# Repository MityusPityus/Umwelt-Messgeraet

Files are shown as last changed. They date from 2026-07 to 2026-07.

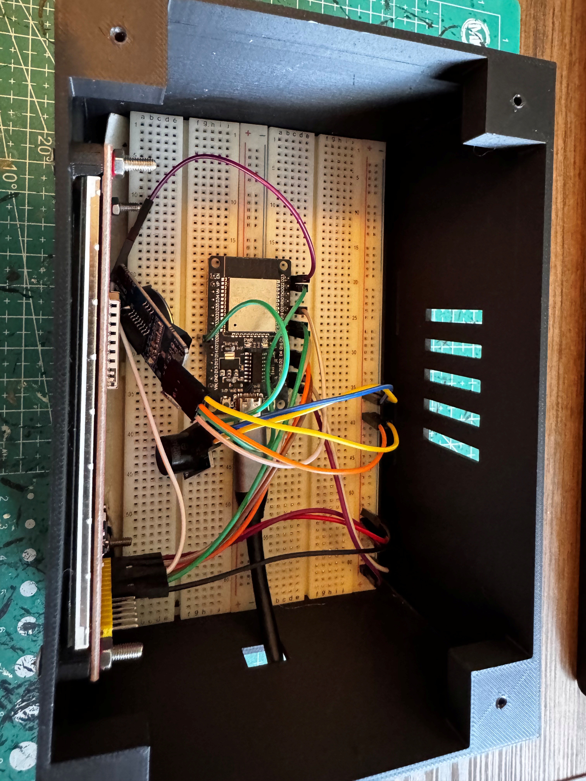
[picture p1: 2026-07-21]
docs/Bilder/Body.jpg

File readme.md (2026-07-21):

# ESP32 Umweltmessstation

Dieses Projekt umfasst die Entwicklung einer offlinefähigen Umweltmessstation auf Basis eines ESP32.

Die Umweltstation misst verschiedene Raumklimawerte, zeigt diese auf einem 4-Zoll-TFT-Display an und kann bei schlechter Luftqualität eine akustische Warnung ausgeben. Zusätzlich besitzt das Gerät eine Touch-Bedienung, eine lokale Datenspeicherung, Statistikfunktionen und ein 3D-gedrucktes Gehäuse.

## Funktionen

- Messung von Temperatur
- Messung der Luftfeuchtigkeit
- Messung des Luftdrucks
- Bewertung der Luftqualität über den Gaswert des BME680
- Anzeige von Uhrzeit und Datum über ein DS3231 RTC-Modul
- Offline-Betrieb ohne Internetverbindung
- Touch-Bedienung über XPT2046
- Akustischer Alarm über Buzzer bei schlechter Luftqualität
- Alarm-Quittierung über Button
- Lokale Messwertspeicherung mit LittleFS
- Statistikansicht für Tages- und 24h-Durchschnitt
- Graphanzeige der letzten 24 Stunden
- Alarm-Protokoll mit Zeitstempel und Messwerten
- Individuell konstruiertes 3D-Gehäuse

## Verwendete Hardware

| Komponente | Zweck |
|---|---|
| ESP32 Dev Board | Zentrale Steuereinheit |
| BME680 | Messung von Temperatur, Feuchtigkeit, Druck und Gaswert |
| DS3231 RTC | Offline-Uhrzeit und Datum |
| ST7796S TFT Display | Anzeige der Messwerte |
| XPT2046 Touchcontroller | Touch-Bedienung |
| Aktiver Buzzer | Akustischer Alarm |
| Push Button | Alarm quittieren |
| 3D-gedrucktes Gehäuse | Schutz und Montage der Komponenten |

## Software-Funktionen

Die Hauptsoftware liest regelmäßig die Sensordaten aus, aktualisiert das Display und bewertet die Luftqualität anhand des Gaswiderstands. Bei schlechter Luftqualität wird ein Alarm ausgelöst, der über einen Button quittiert werden kann.

Die Messwerte werden lokal im internen Flash-Speicher des ESP32 über LittleFS gespeichert. Dadurch ist keine Internetverbindung notwendig. Die gespeicherten Werte werden für Statistik- und Graphfunktionen verwendet.

## Kalibrierung

Während des Projekts wurden die Messwerte mit einem externen Hygrometer verglichen.

Ermittelte Abweichungen:

- Temperatur: Sensor zeigte ca. 3,6 °C zu hoch
- Luftfeuchtigkeit: Sensor lag ca. 3,4 % unter dem Vergleichswert
- Gaswert:
  - Fenster offen: ca. 132,5 kOhm
  - Fenster geschlossen: ca. 88,7 kOhm
  - angepustet: ca. 60 kOhm

Daraus wurden folgende Luftqualitätsbereiche abgeleitet:

| Gaswert | Bewertung |
|---|---|
| >= 100 kOhm | Gut |
| 70 - 99,9 kOhm | Mittel |
| < 70 kOhm | Schlecht |

## Projektstatus

Aktueller Stand:

- Hardware aufgebaut
- RTC-Modul erfolgreich ausgetauscht
- Display und Touch funktionieren
- Sensorwerte werden angezeigt
- Statistik- und Graphfunktionen sind integriert
- Alarm-Protokoll ist integriert
- Gehäuse wurde gedruckt und montiert
- Kurzzeit- und Plausibilitätstests wurden durchgeführt

Der geplante 24h-Dauertest konnte aus Zeitgründen vor der Präsentation nicht vollständig durchgeführt werden. Stattdessen wurde ein mehrstündiger Funktionstest mit Vergleichsmessungen durchgeführt.

## Repository-Struktur

```text
docs/
  Projektdokumentation und Bilder

hardware/
  Bauteilliste, Verkabelung und Hinweise

software/
  Hauptprogramm der Umweltstation

tests/
  Einzeltests für Display, Touch, RTC und BME680

3d-modelle/
  OpenSCAD- und STL-Dateien für das Gehäuse

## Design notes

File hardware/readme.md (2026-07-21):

# Hardware

Dieser Ordner enthält alle hardwarebezogenen Informationen der Umweltmessstation.

## Inhalte

### Bauteilliste.md

Übersicht aller verwendeten Komponenten.

### Verkabelung.md

Dokumentation der Pinbelegung und Verdrahtung zwischen den einzelnen Komponenten.

### Schaltplan.png

Grafische Darstellung der elektrischen Verschaltung des Systems.

## Verwendete Hauptkomponenten

- ESP32 Dev Board
- BME680 Sensor
- DS3231 RTC Modul
- ST7796S Display
- XPT2046 Touchcontroller
- Aktiver Buzzer
- Push Button
- 3D-gedrucktes Gehäuse

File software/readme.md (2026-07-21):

# Software

In diesem Ordner befindet sich der Hauptcode der ESP32 Umweltmessstation.

## Hauptfunktionen

- Initialisierung von Display, Touch, BME680 und RTC
- Anzeige aktueller Messwerte
- Bewertung der Luftqualität
- Alarmfunktion über Buzzer
- Alarmquittierung über Button
- Touch-Navigation
- Statistikscreen
- 24h Graphscreen
- Alarm-Protokoll
- Speicherung der Messwerte mit LittleFS

## Wichtig

Der aktuelle Code verwendet für die Präsentation ein kurzes Speicherintervall:

```cpp
const unsigned long logInterval = 30000;

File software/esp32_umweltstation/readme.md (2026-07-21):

# ESP32 Umweltmessstation Software

Diese Software steuert die komplette Umweltmessstation.

## Hauptfunktionen

### Sensorik

Auslesen des BME680 Sensors:

- Temperatur
- Luftfeuchtigkeit
- Luftdruck
- Gaswert

### Echtzeituhr

Verwendung eines DS3231 RTC-Moduls für:

- Uhrzeit
- Datum

Die Uhr funktioniert vollständig offline und benötigt keine Internetverbindung.

### Anzeige

Darstellung der Messwerte auf einem ST7796S 4-Zoll-TFT-Display.

Angezeigt werden:

- Temperatur
- Luftfeuchtigkeit
- Luftdruck
- Luftqualität
- Uhrzeit
- Datum

### Touchbedienung

Der XPT2046 Touchcontroller ermöglicht:

- Öffnen der Statistikansicht
- Öffnen des 24h-Graphen
- Öffnen des Alarmprotokolls
- Navigation zwischen den Ansichten

### Luftqualitätsbewertung

Die Luftqualität wird anhand des Gaswiderstands des BME680 bewertet.

| Gaswert | Bewertung |
|---|---|
| >= 100 kOhm | Gut |
| 70 - 99.9 kOhm | Mittel |
| < 70 kOhm | Schlecht |

### Alarmfunktion

Bei schlechter Luftqualität:

- Aktivierung des Buzzers
- Anzeige einer Warnung auf dem Display

Der Alarm kann über einen Taster quittiert werden.

### Datenspeicherung

Die Messdaten werden lokal im Flash-Speicher gespeichert.

Verwendete Technologie:

- LittleFS

Die Speicherung erfolgt ohne Internetverbindung.

### Statistik

Folgende Statistiken stehen zur Verfügung:

- Durchschnittswerte des aktuellen Tages
- Durchschnittswerte der letzten 24 Stunden

### Graph

Grafische Darstellung der letzten 24 Stunden für:

- Temperatur
- Luftfeuchtigkeit
- Luftdruck
- Gaswert

### Alarmprotokoll

Speicherung von Alarmereignissen mit:

- Zeitstempel
- Temperatur
- Luftfeuchtigkeit
- Luftdruck
- Gaswert

## Verwendete Bibliotheken

- Adafruit_GFX
- Adafruit_ST7796S
- Adafruit_BME680
- Adafruit_Sensor
- RTClib
- XPT2046_Touchscreen
- LittleFS

## Hauptdatei

```text
esp32_umweltstation.ino

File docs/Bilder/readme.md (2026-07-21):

# Bilder

Dieser Ordner enthält Grafiken, Screenshots und Fotos, die während der Entwicklung der Umweltmessstation erstellt wurden.

## Enthaltene Dateien

### Schaltplan.png

Schaltplan der Umweltmessstation.

Der Schaltplan dokumentiert die elektrische Verbindung zwischen:

- ESP32
- BME680 Sensor
- DS3231 RTC
- ST7796S Display
- XPT2046 Touchcontroller
- Buzzer
- Taster

## Geplante Ergänzungen

Zusätzlich sollen folgende Bilder dokumentiert werden:

- Aufbau auf dem Arbeitstisch
- Verkabelung der Komponenten
- Fertiges Gehäuse
- Hauptbildschirm
- Statistikansicht
- 24h-Graph
- Alarmprotokoll
``

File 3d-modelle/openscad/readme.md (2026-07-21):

# OpenSCAD Modell

Dieser Ordner enthält die CAD-Datei des Gehäuses für die ESP32 Umweltmessstation.

## Datei

### esp32_umweltstation_case.scad

OpenSCAD-Modell des Gehäuses.

Das Gehäuse wurde speziell für die verwendeten Komponenten entwickelt:

- ESP32
- ST7796S 4 Zoll Display
- XPT2046 Touchscreen
- BME680 Sensor
- DS3231 RTC Modul
- Buzzer
- Taster

## Eigenschaften

- Frontausschnitt für das Display
- Befestigungspunkte für die Elektronik
- Öffnungen für Sensorbelüftung
- Öffnung für USB-Kabel
- Platz für RTC und Sensor
- Verschraubbares Gehäuse

## Software

Zur Bearbeitung der CAD-Datei wurde OpenSCAD verwendet.

https://openscad.org

## Hinweis

Die OpenSCAD-Datei stellt die Master-Datei dar und kann für zukünftige Anpassungen weiter bearbeitet werden.

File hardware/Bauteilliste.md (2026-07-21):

# Bauteilliste

## Elektronik

| Komponente | Anzahl | Funktion |
|---|---|---|
| ESP32 Dev Board | 1 | Hauptcontroller |
| BME680 | 1 | Temperatur, Feuchtigkeit, Druck, Gas |
| DS3231 RTC | 1 | Uhrzeit und Datum |
| ST7796S 4 Zoll Display | 1 | Anzeige |
| XPT2046 Touchcontroller | 1 | Touchbedienung |
| Aktiver Buzzer | 1 | Akustische Warnung |
| Push Button | 1 | Alarm quittieren |
| USB Kabel | 1 | Stromversorgung |

## Mechanik

| Komponente | Anzahl |
|---|---|
| Gehäuse Oberteil | 1 |
| Gehäuse Unterteil | 1 |
| Schrauben | 4 |

## Software-Bibliotheken

- Adafruit_GFX
- Adafruit_ST7796S
- Adafruit_BME680
- RTClib
- XPT2046_Touchscreen
- LittleFS

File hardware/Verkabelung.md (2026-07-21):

# Verkabelung

## Display ST7796S

| Pin | ESP32 |
|---|---|
| VCC | 3.3V |
| GND | GND |
| LED | 3.3V |
| SCK | GPIO18 |
| SDI | GPIO23 |
| CS | GPIO5 |
| DC | GPIO2 |
| RST | GPIO4 |

## Touch XPT2046

| Pin | ESP32 |
|---|---|
| CLK | GPIO18 |
| DIN | GPIO23 |
| DO | GPIO19 |
| CS | GPIO27 |
| IRQ | GPIO14 |

## BME680

| Pin | ESP32 |
|---|---|
| SDA | GPIO21 |
| SCL | GPIO22 |
| VCC | 3.3V |
| GND | GND |

## RTC DS3231

| Pin | ESP32 |
|---|---|
| SDA | GPIO21 |
| SCL | GPIO22 |
| VCC | 3.3V |
| GND | GND |

## Buzzer

GPIO26

## Alarmbutton

GPIO13

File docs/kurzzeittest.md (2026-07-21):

# Kurzzeittest

Ein vollständiger 24h Dauertest konnte vor der Präsentation nicht durchgeführt werden.

Stattdessen wurde ein mehrstündiger Test durchgeführt.

## Geprüfte Funktionen

- Display
- Touch
- RTC
- BME680
- Statistik
- Graphanzeige
- Alarmprotokoll
- Buzzer
- Button

## Ergebnis

Alle Kernfunktionen arbeiteten stabil.

Die Sensorwerte wurden erfolgreich mit einem externen Hygrometer verglichen.

Die Luftqualitätsbewertung wurde durch verschiedene Tests überprüft:

- Fenster offen
- Fenster geschlossen
- Angepusteter Sensor

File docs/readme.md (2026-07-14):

# Dokumentation

Enthält Projektdokumentation, Fehleranalysen und Arbeitsprotokolle.

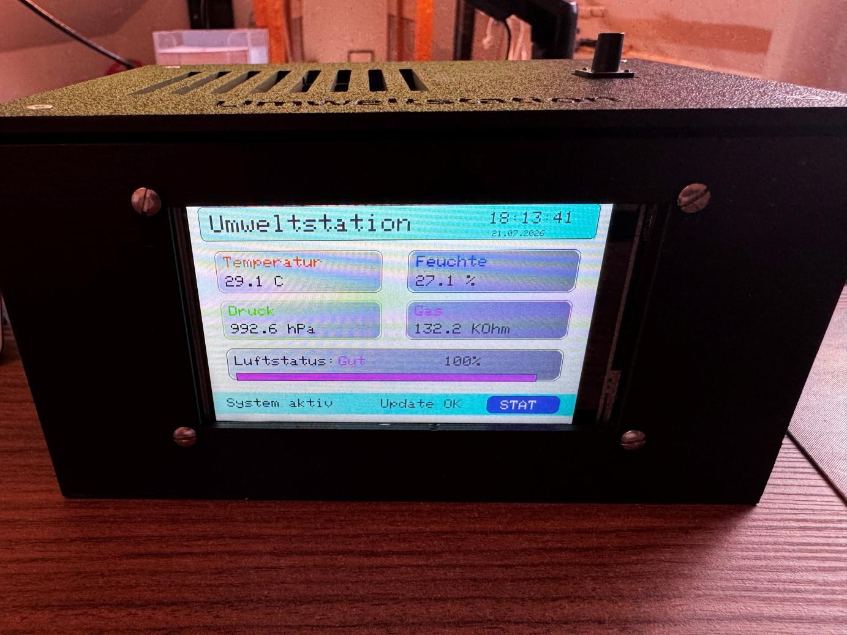
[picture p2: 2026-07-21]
assets/scrumboard-2.png

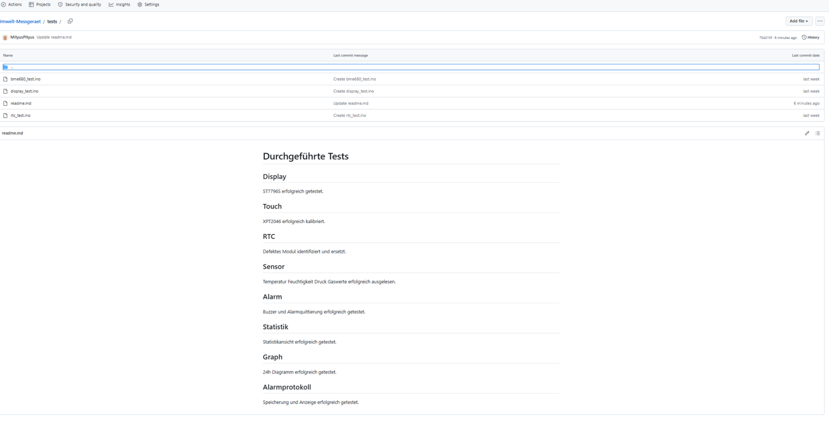
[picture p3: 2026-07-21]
assets/doku-bild-2.jpg

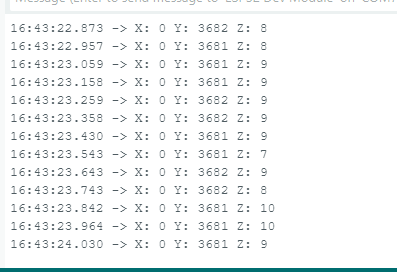
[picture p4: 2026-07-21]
assets/doku-bild-4.jpg

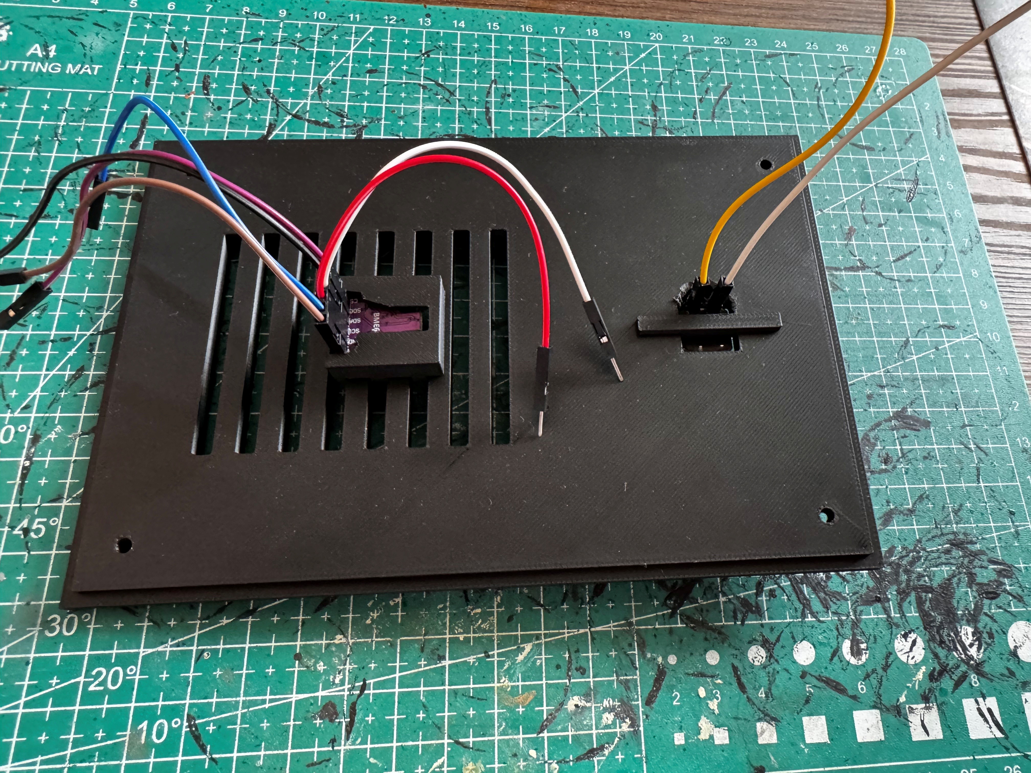
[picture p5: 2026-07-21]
docs/Bilder/Lid.jpg

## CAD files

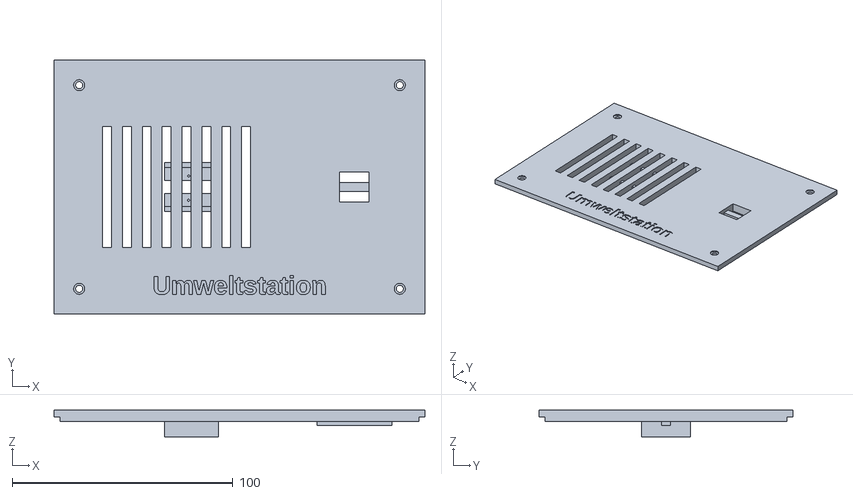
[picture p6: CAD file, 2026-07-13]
3d-modelle/stl/esp32_umweltstation_lid.stl
168.0 x 115.0 x 12.0

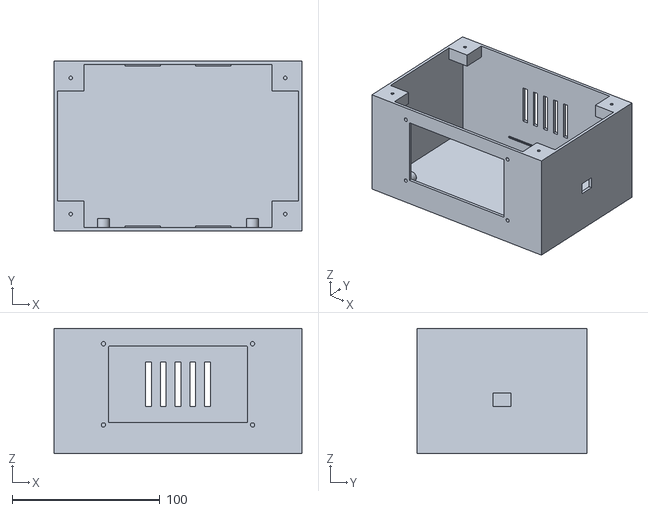
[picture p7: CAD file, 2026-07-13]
3d-modelle/stl/esp32_umweltstation_body.stl
168.0 x 115.0 x 85.0

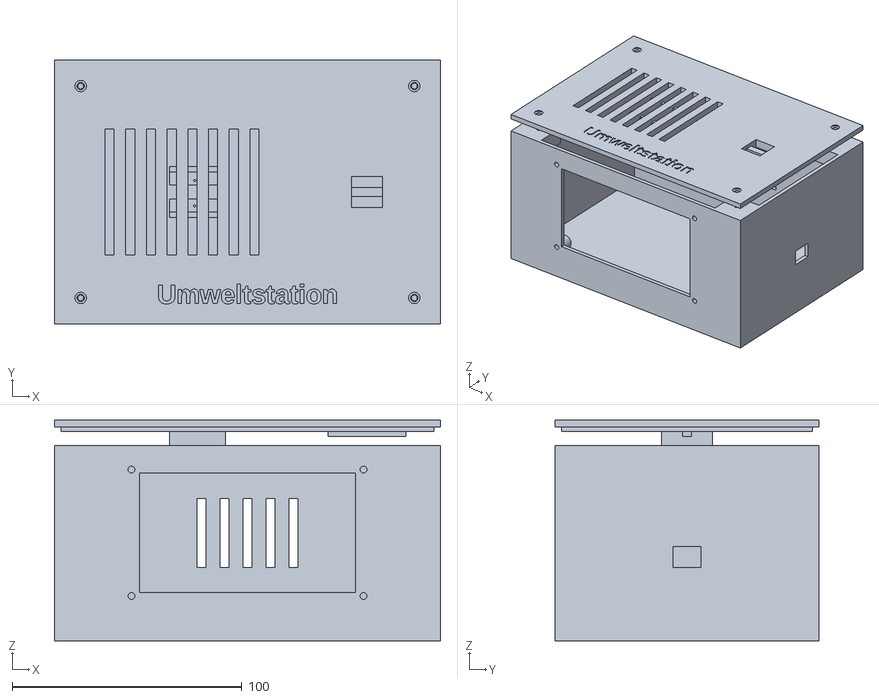
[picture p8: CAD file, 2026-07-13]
3d-modelle/stl/esp32_umweltstation_case.v2.stl
168.0 x 115.0 x 96.0

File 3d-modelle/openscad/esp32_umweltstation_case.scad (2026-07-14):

// ESP32 Umweltstation Gehaeuse V13.6
// Einheiten: mm
// OpenSCAD:
// PART = "preview" -> Vorschau
// PART = "body"    -> Unterteil exportieren
// PART = "lid"     -> Deckel exportieren

PART = "preview"; // "body", "lid", "preview"

// =====================================================
// Hauptmasse
// =====================================================
case_w = 168;
case_d = 115;
case_h = 85;

wall = 2.4;
lid_t = 3.0;
clearance = 0.4;

// =====================================================
// Gravuren
// =====================================================
engraving_enabled = true;

lid_text = "Umweltstation";
lid_text_size = 8.5;
lid_engrave_depth = 0.5;
lid_text_x = case_w / 2;
lid_text_y = 13;

body_bottom_text = "Mityu - Prototype";
body_text_size = 7.0;
body_engrave_depth = 0.5;
body_text_x = case_w / 2;
body_text_y = case_d / 2;

// =====================================================
// Display vorne
// =====================================================
display_center_z = 47;

display_view_w = 94;
display_view_h = 52;

display_pocket_w = 112;
display_pocket_h = 64;
display_recess_depth = 8.5;

display_hole_dx = 101;
display_hole_dz = 55;
display_screw_d = 3.0;

display_post_d = 8.0;
display_post_depth = 6.0;

// =====================================================
// USB rechts
// =====================================================
usb_slot_w = 12;
usb_slot_h = 9;
usb_slot_z = 32;

// =====================================================
// Hintere Zusatz-Lueftung
// =====================================================
// Kleine Schlitze hinten mittig fuer bessere Durchlueftung.
back_vent_count = 5;
back_vent_w = 4;
back_vent_h = 30;
back_vent_gap = 6;
back_vent_center_x = case_w / 2;
back_vent_z = 32;

// =====================================================
// Breadboard Niederhalter / Anti-Wackel-Lippen
// Start jetzt bei 12.7 mm, damit Breadboard leichter reingeht.
// =====================================================
breadboard_clips_enabled = true;

bb_clip_w = 24;
bb_clip_d = 1.0;
bb_clip_h = 0.9;
bb_clip_z = 12.7;
bb_clip_inset_x = 48;

// =====================================================
// Button oben
// =====================================================
button_hole = 13.5;
button_x = case_w - 32;
button_y = case_d / 2;

// Durchgehende Support-Bar fuer Button
button_bar_w = 4;
button_bar_l = 34;
button_bar_h = 4;
button_bar_z = -button_bar_h;

// =====================================================
// Lueftung oben
// =====================================================
vent_count = 8;
vent_w = 4;
vent_l = 55;
vent_gap = 5;
vent_x0 = 22;
vent_y = case_d / 2;

// =====================================================
// Deckelschrauben / Body-Halter
// =====================================================
lid_screw_d = 3.2;
top_boss_pilot_d = 2.5;

top_boss_size = 18;
top_boss_h = 10;
top_boss_z = case_h - top_boss_h;

screw_offset = wall + top_boss_size / 2;

// =====================================================
// BME680 Einschub-Halter am Deckel
// Sensor ca. 20 x 20 x 4 mm
// Links offen fuer Pins/Kabel.
// Innenhoehe ca. 9 mm.
// =====================================================
sensor_board_w = 20;
sensor_board_d = 20;

sensor_clearance = 2.0;

sensor_mount_x = 50;
sensor_mount_y = case_d / 2 - (sensor_board_d + sensor_clearance) / 2;

sensor_slot_w = sensor_board_w + sensor_clearance;
sensor_slot_d = sensor_board_d + sensor_clearance;

sensor_rail_wall = 2.2;
sensor_rail_h = 9.0;

sensor_lip_w = 8.0;
sensor_lip_h = 1.2;

sensor_stop_w = 2.5;

// Kleine Einrast-Nupsis fuer Sensorloecher
// - Durchmesser 1 mm
// - Abstand 11 mm
// - erster Nupsi 5 mm von der ersten Seitenwand/Lippe entfernt
// - zweiter Nupsi 11 mm weiter
sensor_peg_enabled = true;
sensor_peg_d = 1.0;
sensor_peg_h = 4.0;
sensor_peg_spacing = 11.0;
sensor_peg_first_offset = 5.0;

// =====================================================
// Sonstiges
// =====================================================
cut_depth = 20;
holder_overlap = 0.8;

$fn = 48;

// =====================================================
// Positionen Deckelschrauben
// =====================================================
module lid_screw_positions() {
    positions = [
        [screw_offset, screw_offset],
        [case_w - screw_offset, screw_offset],
        [screw_offset, case_d - screw_offset],
        [case_w - screw_offset, case_d - screw_offset]
    ];

    for (p = positions) {
        translate([p[0], p[1], 0])
            children();
    }
}

// =====================================================
// Positionen Display-Schrauben vorne
// =====================================================
module display_screw_positions_front() {
    for (sx = [-1, 1]) {
        for (sz = [-1, 1]) {
            translate([
                case_w / 2 + sx * display_hole_dx / 2,
                0,
                display_center_z + sz * display_hole_dz / 2
            ])
            children();
        }
    }
}

// =====================================================
// Hintere Lueftungsschlitze
// =====================================================
module back_vents_cutout() {
    total_w = back_vent_count * back_vent_w + (back_vent_count - 1) * back_vent_gap;
    start_x = back_vent_center_x - total_w / 2;

    for (i = [0 : back_vent_count - 1]) {
        translate([
            start_x + i * (back_vent_w + back_vent_gap),
            case_d - wall - 2,
            back_vent_z
        ])
            cube([
                back_vent_w,
                wall + 6,
                back_vent_h
            ]);
    }
}

// =====================================================
// Deckel-Gravur oben
// =====================================================
module lid_engraving_cut() {
    if (engraving_enabled) {
        translate([
            lid_text_x,
            lid_text_y,
            lid_t - lid_engrave_depth
        ])
            linear_extrude(height = lid_engrave_depth + 0.3)
                text(
                    lid_text,
                    size = lid_text_size,
                    halign = "center",
                    valign = "center",
                    font = "Liberation Sans:style=Bold"
                );
    }
}

// =====================================================
// Boden-Gravur Body unten
// =====================================================
module body_bottom_engraving_cut() {
    if (engraving_enabled) {
        translate([
            body_text_x,
            body_text_y,
            -0.1
        ])
            linear_extrude(height = body_engrave_depth + 0.3)
                text(
                    body_bottom_text,
                    size = body_text_size,
                    halign = "center",
                    valign = "center",
                    font = "Liberation Sans:style=Bold"
                );
    }
}

// =====================================================
// Gehaeuse-Schale
// =====================================================
module shell_only() {
    difference() {
        cube([case_w, case_d, case_h]);

        // Innenraum offen nach oben
        translate([wall, wall, wall])
            cube([
                case_w - 2 * wall,
                case_d - 2 * wall,
                case_h - wall + 1
            ]);

        // Sichtbares Displayfenster vorne
        translate([
            (case_w - display_view_w) / 2,
            -1,
            display_center_z - display_view_h / 2
        ])
            cube([
                display_view_w,
                wall + 3,
                display_view_h
            ]);

        // Displaytasche innen
        translate([
            (case_w - display_pocket_w) / 2,
            wall,
            display_center_z - display_pocket_h / 2
        ])
            cube([
                display_pocket_w,
                display_recess_depth,
                display_pocket_h
            ]);

        // USB-Schlitz rechts
        translate([
            case_w - wall - 2,
            case_d / 2 - usb_slot_w / 2,
            usb_slot_z
        ])
            cube([
                wall + 6,
                usb_slot_w,
                usb_slot_h
            ]);

        // Hintere Zusatz-Lueftung
        back_vents_cutout();

        // Unterseiten-Gravur
        body_bottom_engraving_cut();
    }
}

// =====================================================
// Breadboard-Niederhalter
// =====================================================
module breadboard_clips() {
    if (breadboard_clips_enabled) {

        // vorne links
        translate([
            bb_clip_inset_x,
            wall,
            bb_clip_z
        ])
            cube([
                bb_clip_w,
                bb_clip_d,
                bb_clip_h
            ]);
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

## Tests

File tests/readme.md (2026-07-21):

# Durchgeführte Tests

Dieser Ordner enthält Testprogramme zur Einzelprüfung der wichtigsten Komponenten der ESP32 Umweltmessstation.

## Testübersicht

| Datei | Zweck | Ergebnis |
|---|---|---|
| i2c_scanner.ino | Prüfung der I2C-Geräte | BME680 und RTC wurden erkannt |
| rtc_test.ino | Test des DS3231 RTC-Moduls | Neues RTC-Modul zählt korrekt hoch |
| bme680_test.ino | Auslesen der Sensordaten | Temperatur, Feuchtigkeit, Druck und Gaswert werden gelesen |
| display_test.ino | Prüfung des ST7796S Displays | Anzeige und Ausrichtung erfolgreich getestet |
| touch_test.ino | Prüfung und Kalibrierung des XPT2046 Touchscreens | Touch funktioniert nach Kalibrierung |
| buzzer_button_test.ino | Prüfung von Buzzer und Button | Alarmton und Quittierung erfolgreich getestet |

## Besonderheiten

### RTC

Das erste RTC-Modul wurde zwar über I2C erkannt, zählte jedoch die Uhrzeit nicht weiter.  
Nach Austausch des Moduls funktionierte die RTC korrekt.

### Touch

Für den Touchscreen wurde zunächst eine andere XPT2046-Bibliothek getestet.  
Die finale Umsetzung verwendet:

```cpp
#include <XPT2046_Touchscreen.h>

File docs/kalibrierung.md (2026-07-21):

# Kalibrierung und Plausibilitätsprüfung

## Vergleichsmessung Temperatur und Luftfeuchtigkeit

Zur Plausibilitätsprüfung wurden die Werte der Umweltmessstation mit einem externen Hygrometer verglichen.

Nach ca. 5 bis 6 Stunden Laufzeit ergaben sich folgende Werte:

| Messgröße | Umweltstation | Hygrometer | Abweichung |
|---|---:|---:|---:|
| Temperatur | 29,2 °C | 25,6 °C | +3,6 °C |
| Luftfeuchtigkeit | 32,6 % | 36,0 % | -3,4 % |

Die Temperaturabweichung ist plausibel, da der BME680 im Gehäuse verbaut ist und Wärme durch ESP32, Display und Sensorheizung beeinflusst wird.

Im Code wurde daher ein Temperatur-Offset von `-3.6 °C` eingebaut.

```cpp
const float TEMP_OFFSET = -3.6;

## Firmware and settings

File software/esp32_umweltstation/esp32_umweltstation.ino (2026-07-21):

#include <SPI.h>
#include <Wire.h>
#include <LittleFS.h>

#include <Adafruit_GFX.h>
#include <Adafruit_ST7796S.h>
#include <Adafruit_Sensor.h>
#include <Adafruit_BME680.h>
#include <XPT2046_Touchscreen.h>

#include "RTClib.h"

// ======================================================
// PINS
// ======================================================

// Display ST7796S
#define TFT_CS   5
#define TFT_DC   2
#define TFT_RST  4

// Touch XPT2046
#define TOUCH_CS   27
#define TOUCH_IRQ  14

// Buzzer + Button
#define BUZZER_PIN 26
#define BUTTON_PIN 13

// I2C ESP32
#define I2C_SDA 21
#define I2C_SCL 22

// SPI:
// SCK  -> GPIO18
// MISO -> GPIO19
// MOSI -> GPIO23

// ======================================================
// OBJEKTE
// ======================================================

Adafruit_ST7796S display(TFT_CS, TFT_DC, TFT_RST);
XPT2046_Touchscreen touch(TOUCH_CS, TOUCH_IRQ);
Adafruit_BME680 bme;
RTC_DS3231 rtc;

// ======================================================
// KALIBRIERUNG
// ======================================================

// Sensor zeigte im Gehaeuse ca. 3.6 C zu hoch
const float TEMP_OFFSET = -3.6;

// Druck erstmal nicht korrigieren.
// Wetter-Apps zeigen oft auf Meeresspiegel reduzierten Luftdruck.
// BME680 misst den absoluten Druck am Standort.
const float PRESSURE_OFFSET = 0.0;

// Luftqualitaet anhand deiner Messwerte:
// Fenster offen: ca. 132.5 kOhm -> Gut
// Fenster geschlossen: ca. 88.7 kOhm -> Mittel
// Angepustet: ca. 60 kOhm -> Schlecht
const float GAS_BAD_THRESHOLD = 70.0;
const float GAS_MEDIUM_THRESHOLD = 100.0;

// ======================================================
// DATEISPEICHER
// ======================================================

const char* LOG_FILE = "/umwelt_log.csv";
const char* ALARM_FILE = "/alarm_log.csv";

// Fuer Praesentation/Test: alle 30 Sekunden speichern.
// Fuer echten Betrieb spaeter auf 300000 stellen.
const unsigned long logInterval = 30000;
// const unsigned long logInterval = 300000;

unsigned long lastLogSave = 0;

// Wir behalten intern bis zu 14 Tage,
// Graph zeigt aber nur die letzten 24 Stunden.
const unsigned long STORAGE_RETENTION_SECONDS = 14UL * 24UL * 60UL * 60UL;
const unsigned long LAST_24H_SECONDS = 24UL * 60UL * 60UL;

// ======================================================
// TIMER
// ======================================================

unsigned long lastSensorUpdate = 0;
unsigned long lastClockUpdate = 0;
unsigned long lastBuzzerToggle = 0;
unsigned long lastButtonPress = 0;
unsigned long lastTouchAction = 0;

const unsigned long sensorUpdateInterval = 2000;
const unsigned long clockUpdateInterval = 1000;
const unsigned long buzzerInterval = 300;
const unsigned long debounceDelay = 250;
const unsigned long touchDebounceDelay = 350;

// ======================================================
// FLICKER FIX FLAGS
// ======================================================

bool statsNeedsRefresh = false;
bool graphNeedsRefresh = false;
bool alarmLogNeedsRefresh = false;

// ======================================================
// ALARM-LOGIK
// ======================================================

bool airBad = false;
bool lastAirBadState = false;
bool alarmMuted = false;
bool buzzerState = false;

// false = normal
// true  = Alarm erzwingen zum Testen
const bool FORCE_ALARM_TEST = false;

// ======================================================
// FARBEN RGB565
// ======================================================

#define BLACK    0x0000
#define WHITE    0xFFFF
#define RED      0xF800
#define GREEN    0x07E0
#define BLUE     0x001F
#define YELLOW   0xFFE0
#define CYAN     0x07FF
#define MAGENTA  0xF81F
#define ORANGE   0xFD20
#define GRAY     0x8410
#define DARKGRAY 0x4208
#define NAVY     0x0010

// ======================================================
// DISPLAY / TOUCH
// ======================================================

const int SCREEN_W = 480;
const int SCREEN_H = 320;

const int DISPLAY_ROTATION = 1;
const int TOUCH_ROTATION = 1;

// Touch-Kalibrierung
int TOUCH_MIN_X = 200;
int TOUCH_MAX_X = 3800;
int TOUCH_MIN_Y = 200;
int TOUCH_MAX_Y = 3800;

bool TOUCH_SWAP_XY = false;
bool TOUCH_INVERT_X = true;
bool TOUCH_INVERT_Y = true;

int TOUCH_OFFSET_X = 12;
int TOUCH_OFFSET_Y = 0;

// ======================================================
// SCREEN MODUS
// ======================================================

enum ScreenMode {
  SCREEN_MAIN,
  SCREEN_STATS,
  SCREEN_GRAPH,
  SCREEN_ALARMS
};

ScreenMode currentScreen = SCREEN_MAIN;

// ======================================================
// GRAPH MODUS
// ======================================================

enum GraphMode {
  GRAPH_TEMP,
  GRAPH_HUM,
  GRAPH_PRESSURE,
  GRAPH_GAS
};

GraphMode currentGraphMode = GRAPH_TEMP;

// ======================================================
// LAYOUT MAIN SCREEN
// ======================================================

const int HEADER_X = 12;
const int HEADER_Y = 18;
const int HEADER_W = 456;
const int HEADER_H = 42;

const int BOX_W = 200;
const int BOX_H = 55;

const int BOX1_X = 25;
const int BOX1_Y = 72;

const int BOX2_X = 255;
const int BOX2_Y = 72;

const int BOX3_X = 25;
const int BOX3_Y = 137;

const int BOX4_X = 255;
const int BOX4_Y = 137;

const int STATUS_X = 25;
const int STATUS_Y = 205;
const int STATUS_W = 430;
const int STATUS_H = 48;

const int FOOTER_X = 0;
const int FOOTER_Y = 272;
const int FOOTER_W = 480;
const int FOOTER_H = 35;

const int STAT_BTN_X = 365;
const int STAT_BTN_Y = 276;
const int STAT_BTN_W = 95;
const int STAT_BTN_H = 28;

// ======================================================
// LAYOUT STATS / GRAPH / ALARM KOMPAKT
// ======================================================

const int BACK_BTN_X = 350;
const int BACK_BTN_Y = 265;
const int BACK_BTN_W = 110;
const int BACK_BTN_H = 34;

const int ALARM_BTN_X = 75;
const int ALARM_BTN_Y = 265;
const int ALARM_BTN_W = 120;
const int ALARM_BTN_H = 34;

const int GRAPH_BTN_X = 210;
const int GRAPH_BTN_Y = 265;
const int GRAPH_BTN_W = 120;
const int GRAPH_BTN_H = 34;

const int GBTN_Y = 232;
const int GBTN_H = 28;

const int GBTN_TEMP_X = 25;
const int GBTN_HUM_X = 130;
const int GBTN_PRESS_X = 235;
const int GBTN_GAS_X = 350;

const int GBTN_W = 95;

// ======================================================
// AKTUELLE SENSORWERTE
// ======================================================

float currentTemp = 0.0;
float currentHum = 0.0;
float currentPressure = 0.0;
float currentGas = 0.0;
bool hasSensorReading = false;

// ======================================================
// STATISTIK SEIT START
// ======================================================

unsigned long statsCount = 0;

float sumTemp = 0.0;
float sumHum = 0.0;
float sumPressure = 0.0;
float sumGas = 0.0;

// ======================================================
// STATISTIK AUS DATEI
// ======================================================

struct AverageStats {
  bool hasData;
  unsigned long count;
  float avgTemp;
  float avgHum;
  float avgPressure;
  float avgGas;
};

struct HourlyPoint {
  bool hasData;
  unsigned long hourNumber;
  float avgTemp;
  float avgHum;
  float avgPressure;
  float avgGas;
};

// ======================================================
// HILFSFUNKTIONEN
// ======================================================

void disableDisplay() {
  digitalWrite(TFT_CS, HIGH);
  delayMicroseconds(5);
}

void disableTouch() {
  digitalWrite(TOUCH_CS, HIGH);
  delayMicroseconds(5);
}

float clampFloat(float value, float minVal, float maxVal) {
  if (value < minVal) return minVal;
  if (value > maxVal) return maxVal;
  return value;
}

int mapGasToPercent(float gasKOhm) {
  gasKOhm = clampFloat(gasKOhm, 50.0, 140.0);
  return (int)((gasKOhm - 50.0) * 100.0 / 90.0);
}

void mapTouchToScreen(int rawX, int rawY, int &screenX, int &screenY) {
  int x = rawX;
  int y = rawY;

  if (TOUCH_SWAP_XY) {
    int temp = x;
    x = y;
    y = temp;
  }

  screenX = map(x, TOUCH_MIN_X, TOUCH_MAX_X, 0, SCREEN_W - 1);
  screenY = map(y, TOUCH_MIN_Y, TOUCH_MAX_Y, 0, SCREEN_H - 1);

  if (TOUCH_INVERT_X) {
    screenX = (SCREEN_W - 1) - screenX;
  }

  if (TOUCH_INVERT_Y) {
    screenY = (SCREEN_H - 1) - screenY;
  }

  screenX = screenX + TOUCH_OFFSET_X;
  screenY = screenY + TOUCH_OFFSET_Y;

  screenX = constrain(screenX, 0, SCREEN_W - 1);
  screenY = constrain(screenY, 0, SCREEN_H - 1);
}

bool isInside(int x, int y, int bx, int by, int bw, int bh) {
  return (
    x >= bx &&
    x <= bx + bw &&
    y >= by &&
    y <= by + bh
  );
}

void showStartupMessage(const char* msg, uint16_t color) {
  disableTouch();

  display.fillScreen(BLACK);
  display.setTextColor(color, BLACK);
  display.setTextSize(3);
  display.setCursor(35, 135);
  display.print(msg);
}

// ======================================================
// CSV HELPER
// ======================================================

String getCsvField(String line, int index) {
  int currentIndex = 0;
  int start = 0;

  for (int i = 0; i <= line.length(); i++) {
    if (i == line.length() || line.charAt(i) == ';') {
      if (currentIndex == index) {
        return line.substring(start, i);
      }

      currentIndex++;
      start = i + 1;
    }
  }

  return "";
}

bool parseLogLine(String line, unsigned long &epoch, float &temp, float &hum, float &pressure, float &gas) {
  line.trim();

  if (line.length() < 5) {
    return false;
  }

  if (line.startsWith("epoch")) {
    return false;
  }

  String f0 = getCsvField(line, 0);
  String f1 = getCsvField(line, 1);
  String f2 = getCsvField(line, 2);
  String f3 = getCsvField(line, 3);
  String f4 = getCsvField(line, 4);

  if (f0.length() == 0 || f1.length() == 0 || f2.length() == 0 || f3.length() == 0 || f4.length() == 0) {
    return false;
  }

  epoch = strtoul(f0.c_str(), NULL, 10);
  temp = f1.toFloat();
  hum = f2.toFloat();
  pressure = f3.toFloat();
  gas = f4.toFloat();

  return true;
}

bool parseAlarmLine(String line, unsigned long &epoch, float &temp, float &hum, float &pressure, float &gas, String &status) {
  line.trim();

  if (line.length() < 5) {
    return false;
  }

  if (line.startsWith("epoch")) {
    return false;
  }

  String f0 = getCsvField(line, 0);
  String f1 = getCsvField(line, 1);
  String f2 = getCsvField(line, 2);
  String f3 = getCsvField(line, 3);
  String f4 = getCsvField(line, 4);
  String f5 = getCsvField(line, 5);

  if (f0.length() == 0 || f1.length() == 0 || f2.length() == 0 || f3.length() == 0 || f4.length() == 0) {
    return false;
  }

  epoch = strtoul(f0.c_str(), NULL, 10);
  temp = f1.toFloat();
  hum = f2.toFloat();
  pressure = f3.toFloat();
  gas = f4.toFloat();
  status = f5;

  return true;
}

unsigned long getHourNumber(unsigned long epoch) {
  return epoch / 3600UL;
}

// ======================================================
// LITTLEFS
// ======================================================

void initStorage() {
  if (!LittleFS.begin(true)) {
    Serial.println("LittleFS konnte nicht gestartet werden.");
    return;
  }

  Serial.println("LittleFS gestartet.");

  if (!LittleFS.exists(LOG_FILE)) {
    File file = LittleFS.open(LOG_FILE, FILE_WRITE);
    if (file) {
      file.println("epoch;temp;hum;pressure;gas");
      file.close();
      Serial.println("Mess-Logdatei erstellt.");
    }
  }

  if (!LittleFS.exists(ALARM_FILE)) {
    File file = LittleFS.open(ALARM_FILE, FILE_WRITE);
    if (file) {
      file.println("epoch;temp;hum;pressure;gas;status");
      file.close();
      Serial.println("Alarm-Logdatei erstellt.");
    }
  }
}

void saveMeasurementToLog() {
  if (!hasSensorReading) {
    return;
  }

  DateTime now = rtc.now();
  unsigned long epoch = now.unixtime();

  File file = LittleFS.open(LOG_FILE, FILE_APPEND);

  if (!file) {
    Serial.println("Logdatei konnte nicht geoeffnet werden.");
    return;
  }

  file.print(epoch);
  file.print(";");
  file.print(currentTemp, 2);
  file.print(";");
  file.print(currentHum, 2);
  file.print(";");
  file.print(currentPressure, 2);
  file.print(";");
  file.println(currentGas, 2);

  file.close();

  Serial.println("Messwert gespeichert.");
}

void saveAlarmToLog(const char* statusText) {
  if (!hasSensorReading) {
    return;
  }

  DateTime now = rtc.now();
  unsigned long epoch = now.unixtime();

  File file = LittleFS.open(ALARM_FILE, FILE_APPEND);

  if (!file) {
    Serial.println("Alarmdatei konnte nicht geoeffnet werden.");
    return;
  }

  file.print(epoch);
  file.print(";");
  file.print(currentTemp, 2);
  file.print(";");
  file.print(currentHum, 2);
  file.print(";");
  file.print(currentPressure, 2);
  file.print(";");
  file.print(currentGas, 2);
  file.print(";");
  file.println(statusText);

  file.close();

  alarmLogNeedsRefresh = true;

  Serial.println("Alarmereignis gespeichert.");
}

void pruneOldLogEntries() {
  DateTime now = rtc.now();
  unsigned long nowEpoch = now.unixtime();

  if (!LittleFS.exists(LOG_FILE)) {
    return;
  }

  File input = LittleFS.open(LOG_FILE, FILE_READ);
  File output = LittleFS.open("/temp_log.csv", FILE_WRITE);

  if (!input || !output) {
    Serial.println("Prune Messlog fehlgeschlagen.");

    if (input) input.close();
    if (output) output.close();

    return;
  }

  output.println("epoch;temp;hum;pressure;gas");

  while (input.available()) {
    String line = input.readStringUntil('\n');
    line.trim();

    unsigned long epoch;
    float temp;
    float hum;
    float pressure;
    float gas;

    if (parseLogLine(line, epoch, temp, hum, pressure, gas)) {
      if (epoch <= nowEpoch && nowEpoch - epoch <= STORAGE_RETENTION_SECONDS) {
        output.println(line);
      }
    }
  }

  input.close();
  output.close();

  LittleFS.remove(LOG_FILE);
  LittleFS.rename("/temp_log.csv", LOG_FILE);

  Serial.println("Alte Mess-Logeintraege entfernt.");
}

void pruneOldAlarmEntries() {
  DateTime now = rtc.now();
  unsigned long nowEpoch = now.unixtime();

  if (!LittleFS.exists(ALARM_FILE)) {
    return;
  }

  File input = LittleFS.open(ALARM_FILE, FILE_READ);
  File output = LittleFS.open("/temp_alarm.csv", FILE_WRITE);

  if (!input || !output) {
    Serial.println("Prune Alarmlog fehlgeschlagen.");

    if (input) input.close();
    if (output) output.close();

    return;
  }

  output.println("epoch;temp;hum;pressure;gas;status");

  while (input.available()) {
    String line = input.readStringUntil('\n');
    line.trim();

    unsigned long epoch;
    float temp;
    float hum;
    float pressure;
    float gas;
    String status;

    if (parseAlarmLine(line, epoch, temp, hum, pressure, gas, status)) {
      if (epoch <= nowEpoch && nowEpoch - epoch <= STORAGE_RETENTION_SECONDS) {
        output.println(line);
      }
    }
  }

  input.close();
  output.close();

  LittleFS.remove(ALARM_FILE);
  LittleFS.rename("/temp_alarm.csv", ALARM_FILE);

  Serial.println("Alte Alarm-Logeintraege entfernt.");
}

// ======================================================
// STATISTIK AUS LOG
// ======================================================

AverageStats makeEmptyAverageStats() {
  AverageStats result;
  result.hasData = false;
  result.count = 0;
  result.avgTemp = 0;
  result.avgHum = 0;
  result.avgPressure = 0;
  result.avgGas = 0;
  return result;
}

AverageStats calculateAverageForRange(unsigned long fromEpoch, unsigned long toEpoch) {
  AverageStats result = makeEmptyAverageStats();

  float sTemp = 0;
  float sHum = 0;
  float sPressure = 0;
  float sGas = 0;

  File file = LittleFS.open(LOG_FILE, FILE_READ);

  if (!file) {
    return result;
  }

  while (file.available()) {
    String line = file.readStringUntil('\n');
    line.trim();

    unsigned long epoch;
    float temp;
    float hum;
    float pressure;
    float gas;

    if (parseLogLine(line, epoch, temp, hum, pressure, gas)) {
      if (epoch >= fromEpoch && epoch <= toEpoch) {
        sTemp += temp;
        sHum += hum;
        sPressure += pressure;
        sGas += gas;
        result.count++;
      }
    }
  }

  file.close();

  if (result.count > 0) {
    result.hasData = true;
    result.avgTemp = sTemp / result.count;
    result.avgHum = sHum / result.count;
    result.avgPressure = sPressure / result.count;
    result.avgGas = sGas / result.count;
  }

  return result;
}

AverageStats calculateTodayAverage() {
  DateTime now = rtc.now();
  DateTime startOfDay(now.year(), now.month(), now.day(), 0, 0, 0);

  return calculateAverageForRange(startOfDay.unixtime(), now.unixtime());
}

AverageStats calculateLast24HoursAverage() {
  DateTime now = rtc.now();
  unsigned long nowEpoch = now.unixtime();
  unsigned long fromEpoch = nowEpoch - LAST_24H_SECONDS;

  return calculateAverageForRange(fromEpoch, nowEpoch);
}

void calculateHourlyPoints(HourlyPoint points[24]) {
  for (int i = 0; i < 24; i++) {
    points[i].hasData = false;
    points[i].hourNumber = 0;
    points[i].avgTemp = 0;
    points[i].avgHum = 0;
    points[i].avgPressure = 0;
    points[i].avgGas = 0;
  }

  DateTime now = rtc.now();
  unsigned long currentHour = getHourNumber(now.unixtime());

  float sumTemp[24];
  float sumHum[24];
  float sumPressure[24];
  float sumGas[24];
  unsigned long count[24];

  for (int i = 0; i < 24; i++) {
    sumTemp[i] = 0;
    sumHum[i] = 0;
    sumPressure[i] = 0;
    sumGas[i] = 0;
    count[i] = 0;

    unsigned long hourNum = currentHour - (23 - i);
    points[i].hourNumber = hourNum;
  }

  File file = LittleFS.open(LOG_FILE, FILE_READ);

  if (!file) {
    return;
  }

  while (file.available()) {
    String line = file.readStringUntil('\n');
    line.trim();

    unsigned long epoch;
    float temp;
    float hum;
    float pressure;
    float gas;

    if (parseLogLine(line, epoch, temp, hum, pressure, gas)) {
      unsigned long hourNum = getHourNumber(epoch);

      for (int i = 0; i < 24; i++) {
        if (points[i].hourNumber == hourNum) {
          sumTemp[i] += temp;
          sumHum[i] += hum;
          sumPressure[i] += pressure;
          sumGas[i] += gas;
          count[i]++;
          break;
        }
      }
    }
  }

  file.close();

  for (int i = 0; i < 24; i++) {
    if (count[i] > 0) {
      points[i].hasData = true;
      points[i].avgTemp = sumTemp[i] / count[i];
      points[i].avgHum = sumHum[i] / count[i];
      points[i].avgPressure = sumPressure[i] / count[i];
      points[i].avgGas = sumGas[i] / count[i];
    }
  }
}

float getGraphValue(HourlyPoint p, GraphMode mode) {
  if (mode == GRAPH_TEMP) return p.avgTemp;
  if (mode == GRAPH_HUM) return p.avgHum;
  if (mode == GRAPH_PRESSURE) return p.avgPressure;
  if (mode == GRAPH_GAS) return p.avgGas;

  return 0;
}

const char* getGraphTitle(GraphMode mode) {
  if (mode == GRAPH_TEMP) return "Temperatur";
  if (mode == GRAPH_HUM) return "Feuchte";
  if (mode == GRAPH_PRESSURE) return "Druck";
  if (mode == GRAPH_GAS) return "Gas";

  return "";
}

const char* getGraphUnit(GraphMode mode) {
  if (mode == GRAPH_TEMP) return "C";
  if (mode == GRAPH_HUM) return "%";
  if (mode == GRAPH_PRESSURE) return "hPa";
  if (mode == GRAPH_GAS) return "KOhm";

  return "";
}

uint16_t getGraphColor(GraphMode mode) {
  if (mode == GRAPH_TEMP) return ORANGE;
  if (mode == GRAPH_HUM) return CYAN;
  if (mode == GRAPH_PRESSURE) return MAGENTA;
  if (mode == GRAPH_GAS) return GREEN;

  return WHITE;
}

// ======================================================
// MAIN SCREEN
// ======================================================

void drawHeader() {
  disableTouch();

  display.fillRect(HEADER_X, HEADER_Y, HEADER_W, HEADER_H, NAVY);
  display.drawRoundRect(HEADER_X, HEADER_Y, HEADER_W, HEADER_H, 7, WHITE);

  display.setTextColor(WHITE, NAVY);
  display.setTextSize(3);
  display.setCursor(25, 28);
  display.print("Umweltstation");

  display.setTextSize(2);
  display.setCursor(345, 27);
  display.print("--:--:--");

  display.setTextSize(1);
  display.setCursor(350, 49);
  display.print("--.--.----");
}

void updateClock() {
  if (currentScreen != SCREEN_MAIN) {
    return;
  }

  DateTime now = rtc.now();

  disableTouch();

  display.fillRect(335, 23, 125, 34, NAVY);
  display.setTextColor(WHITE, NAVY);

  display.setTextSize(2);
  display.setCursor(345, 27);

  if (now.hour() < 10) display.print("0");
  display.print(now.hour());
  display.print(":");

  if (now.minute() < 10) display.print("0");
  display.print(now.minute());
  display.print(":");

  if (now.second() < 10) display.print("0");
  display.print(now.second());

  display.setTextSize(1);
  display.setCursor(350, 49);

  if (now.day() < 10) display.print("0");
  display.print(now.day());
  display.print(".");

  if (now.month() < 10) display.print("0");
  display.print(now.month());
  display.print(".");

  display.print(now.year());
}

void drawBox(int x, int y, int w, int h, uint16_t borderColor, const char* title, uint16_t titleColor) {
  disableTouch();

  display.drawRoundRect(x, y, w, h, 8, borderColor);
  display.fillRoundRect(x + 2, y + 2, w - 4, h - 4, 8, DARKGRAY);

  display.setTextColor(titleColor, DARKGRAY);
  display.setTextSize(2);
  display.setCursor(x + 10, y + 7);
  display.print(title);
}
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
void loop() {
  handleTouch();

  handleButton();
  handleBuzzer();

  if (millis() - lastClockUpdate >= clockUpdateInterval) {
    lastClockUpdate = millis();
    updateClock();
  }

  if (millis() - lastSensorUpdate >= sensorUpdateInterval) {
    lastSensorUpdate = millis();
    updateSensorData();
  }

  handleLogging();

  if (currentScreen == SCREEN_STATS && statsNeedsRefresh) {
    statsNeedsRefresh = false;
    drawStatsScreen();
  }

  if (currentScreen == SCREEN_GRAPH && graphNeedsRefresh) {
    graphNeedsRefresh = false;
    drawGraphScreen();
  }

  if (currentScreen == SCREEN_ALARMS && alarmLogNeedsRefresh) {
    alarmLogNeedsRefresh = false;
    drawAlarmLogScreen();
  }
}

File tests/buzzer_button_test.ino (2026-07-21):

#define BUZZER_PIN 26
#define BUTTON_PIN 13

bool buzzerState = false;
bool alarmActive = false;

unsigned long lastButtonPress = 0;
const unsigned long debounceDelay = 250;

void setup() {
  Serial.begin(115200);
  delay(1000);

  pinMode(BUZZER_PIN, OUTPUT);
  digitalWrite(BUZZER_PIN, LOW);

  pinMode(BUTTON_PIN, INPUT_PULLUP);

  Serial.println("Buzzer + Button Test startet...");
  Serial.println("Button druecken: Alarm an/aus");
}

void loop() {
  bool buttonPressed = (digitalRead(BUTTON_PIN) == LOW);

  if (buttonPressed && millis() - lastButtonPress > debounceDelay) {
    lastButtonPress = millis();

    alarmActive = !alarmActive;

    if (alarmActive) {
      Serial.println("Alarm aktiviert.");
    } else {
      Serial.println("Alarm deaktiviert.");
      digitalWrite(BUZZER_PIN, LOW);
      buzzerState = false;
    }
  }

  if (alarmActive) {
    buzzerState = !buzzerState;
    digitalWrite(BUZZER_PIN, buzzerState ? HIGH : LOW);
    delay(300);
  } else {
    digitalWrite(BUZZER_PIN, LOW);
  }
}

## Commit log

2026-07-13 Add files via upload
    Enthält die STL des Demo-Cases für die Umweltstation. Achtung ist das Preview. Die Gesamt ansicht.
    [esp32_umweltstation_case.v2.stl]
2026-07-13 Add files via upload
    Enthält die STL für die "Body" der Umweltstation.
    [esp32_umweltstation_body.stl]
2026-07-13 Add files via upload
    Enthält die STL Datei für den "Lid(Kopf)" für die Umweltstation.
    [esp32_umweltstation_lid.stl]
2026-07-13 Create Arduino-Code-Umweltstat.
2026-07-13 Add files via upload
    Beinhaltet die STL-Datei der Umwelt Station als "Preview" also ganzes.
    [esp32_umweltstation_case.v2.stl]
2026-07-13 Add files via upload
    Beinhaltet die STL-Datei "Body" für die Umweltstation. Der untere Teil des Cases.
    [esp32_umweltstation_body.stl]
2026-07-13 Add files via upload
    Beinhaltet die STL-Datei "Lid" die Oberseite der Umweltstation.
    [esp32_umweltstation_lid.stl]
2026-07-14 Add files via upload
    STL-Datei für den "Body" Part für die Umweltstation.
    [esp32_umweltstation_body.stl]
2026-07-14 Add files via upload
    Datei mit Code für Umweltstation für OPENSCAD
    [esp32_umweltstation_case.scad]
